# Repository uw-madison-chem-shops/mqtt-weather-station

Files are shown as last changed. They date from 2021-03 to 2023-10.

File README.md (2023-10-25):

# MQTT weather station

Simple station for monitoring environmental conditions in the lab over MQTT.

Based on the Bosch's [BME280 humidity, pressure, and temperature sensor](https://www.bosch-sensortec.com/products/environmental-sensors/humidity-sensors-bme280/).
Using Adafruit's [breakout board](https://www.adafruit.com/product/2652).

Designed to work with [mqtt.chem.wisc.edu](https://mqtt.chem.wisc.edu/).

## Repository

This is an open source hardware project licensed under the CERN Open Hardware Licence Version 2 - Permissive.
Please see the LICENSE file for the complete license.

This repository is being mirrored to several version control systems in an attempt to ensure maximum avaliability.

| name | url |
| --- | --- |
| blaise | https://git.blaise.zone/uw-madison-chem-shops/mqtt-weather-station.git/about/ |
| Codeberg | https://codeberg.org/uw-madison-chem-shops/mqtt-weather-station |
| GitHub (primary) | https://github.com/uw-madison-chem-shops/mqtt-weather-station |
| GitLab | https://gitlab.com/uw-madison-chem-shops/mqtt-weather-station |

## PCB

This PCB was designed using KiCAD version 5.
Refer to `weather.pdf` for schematic.
PCB images generated with [tracespace](https://github.com/tracespace/tracespace) follow.




## Bill of Materials

| reference | value | manufacturer | part number | price  | vendors |
| :--- | :--- | :--- | :--- | :----- | :--- |
| A1 | ESP8266 breakout | Adafruit | 2471 | $10.00 | [Adafruit](https://www.adafruit.com/product/2471) [DigiKey](https://www.digikey.com/en/products/detail/adafruit-industries-llc/2471/5355489) |
| C1 | 100u | Illinois Cap. | 107KXM025M | $0.25  | [DigiKey](https://www.digikey.com/en/products/detail/illinois-capacitor/107KXM025M/5410757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) |
| C2 | 10u | Yageo | CC1206KKX7R8BB106 | $0.25  | [DigiKey](https://www.digikey.com/en/products/detail/yageo/CC1206KKX7R8BB106/5195365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) |
| C3 | 22u | Yageo | CC1206MKX7R7BB226 | $0.75  | [DigiKey](https://www.digikey.com/en/products/detail/yageo/CC1206MKX7R7BB226/7071713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) |
| C4, C5 | 1u | | | | |
| D1, D2 | red LED | Lite-ON | LTST-C230KRKT | $0.50  | [DigiKey](https://www.digikey.com/en/products/detail/lite-on-inc/LTST-C230KRKT/386857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) |
| J1 | barrel jack | | | $1.00  | |
| PS1 | VXO7805-500-M | | | $3.00  | |
| Q1, Q2 | MOSFET N-ENH | Diodes Inc. | 2N7002K-7 | $0.25  | [DigiKey](https://www.digikey.com/en/products/detail/diodes-incorporated/2N7002K-7/1934378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) [Mouser](https://www.mouser.com/ProductDetail/Diodes-Incorporated/2N7002K-7?qs=rGAXPo9uwV0%2Fp9r5KJ7huA%3D%3D) |
| R1, R2 | 1k |
| R3, R4, R7, R8 | 4.7k |
| R5 | 470k |
| R6, R9 | 1M |
| U1 | BME280 breakout  | Adafruit | 2652 | $20.00 | [Adafruit](https://www.adafruit.com/product/2652) [DigiKey]() |
| U2 | counter | TI | CD4060BM96 | $0.50  |

All prices are extended.
Assuming an order of 10 PCBs, the boards themselves should cost around $5 each.

## Firmware

This project uses [micropython](https://micropython.org/), specifically [microhomie](https://github.com/microhomie/microhomie).
Refer to the "firmware" directory in this repository for detailed instructions.

## Changelog

#### Fixed
- value of C5

### Unprinted

### B

#### Added
- new hour long reset timer based on CD4060BM96

#### Changed
- SOT23 packages for all discrete transistors

### A

#### Added
- initial design

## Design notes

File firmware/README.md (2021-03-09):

# mqtt-weather-station firmware

This project uses [micropython](https://micropython.org/), specifically [microhomie](https://github.com/microhomie/microhomie). Currently we build on microhomie-esp8266-v3.0.2, the binary is in the folder.

You must define the private information defined in `settings.py`. Copy `settings.py.example` to make a folder `settings.py` and define all relevant variables.

Run `flash.sh` to flash the board. You will need [esptool](https://github.com/espressif/esptool) and [ampy](https://github.com/scientifichackers/ampy).

We recommend an [FTDI Basic Breakout](https://www.sparkfun.com/products/9716) to physically program the ESP8266.

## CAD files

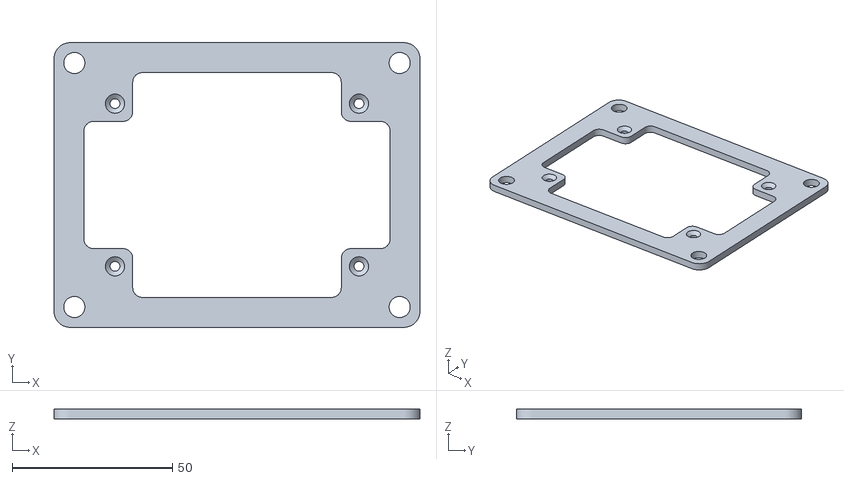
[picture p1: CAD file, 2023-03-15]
adapter-plate/adapter-plate.stl
114.3 x 88.9 x 3.00

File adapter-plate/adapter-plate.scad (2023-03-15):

$fn=50;
inch = 25.4;

module roundedRect(size, radius)
{
        x = size[0];
        y = size[1];
        z = size[2];

        linear_extrude(height=z)
        hull()
        {
                // place 4 circles in the corners, with the given radius
                translate([(-x/2)+radius, (-y/2)+radius, 0])
                circle(r=radius);

                translate([(x/2)-radius, (-y/2)+radius, 0])
                circle(r=radius);

                translate([(-x/2) + radius, (y/2)-radius, 0])
                circle(r=radius);

                translate([(x/2)-radius, (y/2)-radius, 0])
                circle(r=radius);
        }

}

module counterSunk(position, radius)
{
union()
    {
     translate(position)
     union()
        {
     cylinder(3, radius, radius, 8, center=false);
     cylinder(3, 0, 3, center=false);
        }
    }
    
}

difference()
{
roundedRect([4.5*inch, 3.5*inch, 3], 5, center=false);

translate([-4*inch/2, -3*inch/2, 0])
cylinder(3, 0.13*inch, 0.13*inch, 8, center=false);
    
translate([-4*inch/2, 3*inch/2, 0])
cylinder(3, 0.13*inch, 0.13*inch, 8, center=false);
    
translate([4*inch/2, -3*inch/2, 0])
cylinder(3, 0.13*inch, 0.13*inch, 8, center=false);
    
translate([4*inch/2, 3*inch/2, 0])
cylinder(3, 0.13*inch, 0.13*inch, 8, center=false);

counterSunk([3*inch/2, 2*inch/2, 0], 0.06*inch);
counterSunk([-3*inch/2, 2*inch/2, 0], 0.06*inch);
counterSunk([3*inch/2, -2*inch/2, 0], 0.06*inch);
counterSunk([-3*inch/2, -2*inch/2, 0], 0.06*inch);



linear_extrude(height=5)
offset(r=3){
offset(r=-6){
union(){
square([4*inch,1.8*inch], center=true);
square([2.8*inch,3*inch], center=true);
}
}
}
}

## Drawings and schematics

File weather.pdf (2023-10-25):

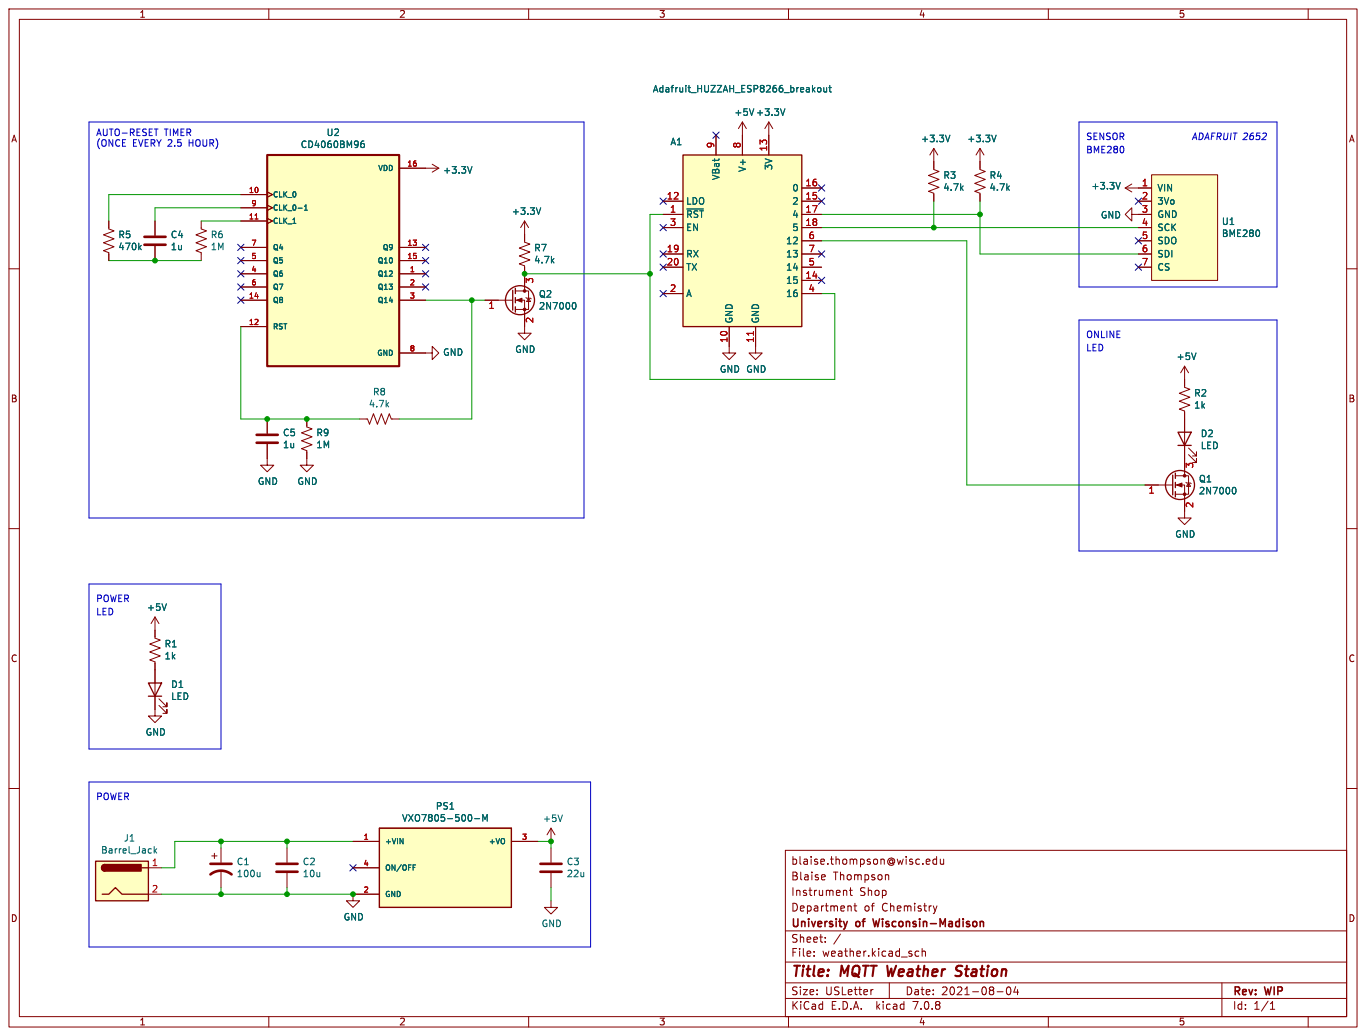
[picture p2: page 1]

ADAFRUIT 2652 AUTO-RESET TIMER

blaise.thompson@wisc.edu

Id: 1/1 Title: MQTT Weather Station

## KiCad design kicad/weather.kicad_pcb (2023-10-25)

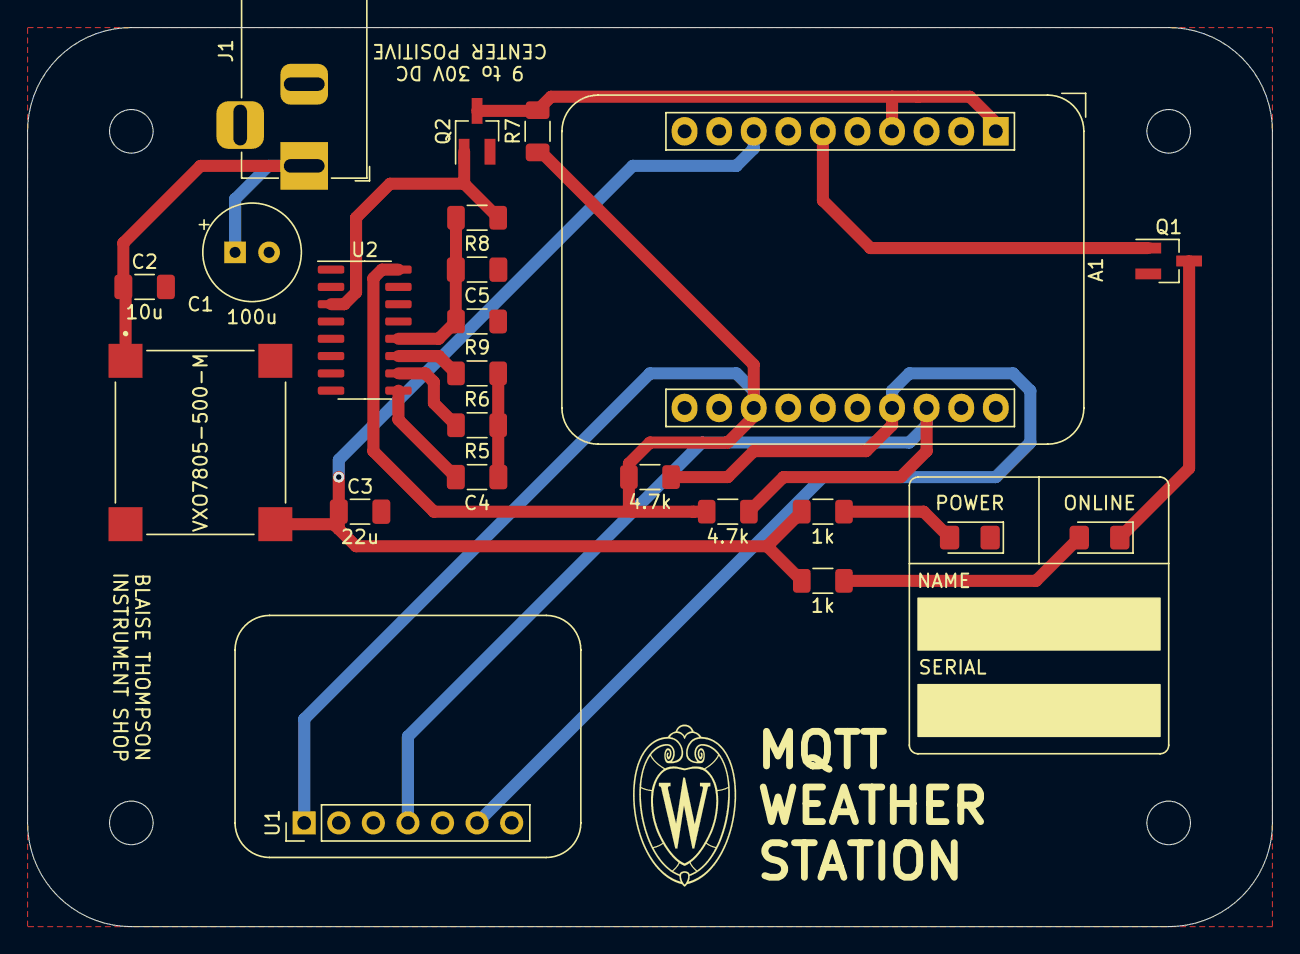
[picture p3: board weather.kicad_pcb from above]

Board: 2 copper layers, 91.4 x 66.0 mm, 23 parts (0 on the bottom side), 17 nets.

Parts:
A1: Adafruit_HUZZAH_ESP8266_breakout
C1: 100u; CP_Radial_Tantal_D7.0mm_P2.50mm
C2: 10u; C_1206_3216Metric_Pad1.33x1.80mm_HandSolder
C3: 22u; C_1206_3216Metric_Pad1.33x1.80mm_HandSolder
C4: 1n; C_1206_3216Metric_Pad1.33x1.80mm_HandSolder
C5: C; C_1206_3216Metric_Pad1.33x1.80mm_HandSolder
D1, D2: LED; LED_1206_3216Metric_Pad1.42x1.75mm_HandSolder
J1: Barrel_Jack; BarrelJack_Horizontal
PS1: VXO7805-500-M; CONV_VXO7805-500-M
Q1, Q2: 2N7000; SOT-23_Handsoldering
R1, R2: 1k; R_1206_3216Metric_Pad1.30x1.75mm_HandSolder
R3, R4: 4.7k; R_1206_3216Metric_Pad1.30x1.75mm_HandSolder
R5: 100k; R_1206_3216Metric_Pad1.30x1.75mm_HandSolder
R6: 1M; R_1206_3216Metric_Pad1.30x1.75mm_HandSolder
R7, R8, R9: R_US; R_1206_3216Metric_Pad1.30x1.75mm_HandSolder
U1: BME280; PinHeader_1x07_P2.54mm_Vertical
U2: CD4060BM96; SOIC-16_3.9x9.9mm_P1.27mm

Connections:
+3V3: A1.13, R3.1, R4.1, R7.1, U1.1, U2.16
+5V: A1.8, C3.1, PS1.3, R1.1, R2.1
GND: A1.10, A1.11, C1.2, C2.2, C3.2, C5.2, D1.1, J1.2, PS1.2, Q1.2, Q2.2, R9.2, U1.3, U2.8
unnamed: A1.1, A1.4, Q2.3, R7.2
unnamed: A1.6, Q1.1
unnamed: A1.17, R4.2, U1.6
unnamed: A1.18, R3.2, U1.4
unnamed: C1.1, C2.1, J1.1, PS1.1
unnamed: C4.1, U2.9
unnamed: C4.2, R5.1, R6.1
unnamed: C5.1, R8.2, R9.1, U2.12
unnamed: D1.2, R1.2
unnamed: D2.1, Q1.3
unnamed: D2.2, R2.2
unnamed: Q2.1, R8.1, U2.3
unnamed: R5.2, U2.10
unnamed: R6.2, U2.11

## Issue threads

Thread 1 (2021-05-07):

Q1 pin assignments wrong

untzag, 2021-05-07:
I believe the pin assignments for Q1 are wrong---should look more closely.

Closed 2021-08-04.

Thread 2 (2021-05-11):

C4 incorrect value for time constant

leobrunette, 2021-05-11:
C4 is currently 1nF which results in a time constant of 0.23ms. Desired time constant is 0.23s, to achieve C4 should be replaced with a 1uF capacitor.

Closed 2021-08-04.

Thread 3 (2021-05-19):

R5 value incorrect

leobrunette, 2021-05-19:
R5 value is currently 100k, this needs to be doubled (to obtain 1 hour reset).

untzag, 2021-05-25:
Correct value 470k

Closed 2021-05-25.

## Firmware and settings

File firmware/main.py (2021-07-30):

import settings

import sys
import machine
from machine import Pin, I2C, WDT
import network
import time
import struct

import mqtt_as
mqtt_as.MQTT_base.DEBUG = True


from bme280 import BME280

from homie.constants import FALSE, TRUE, BOOLEAN, FLOAT, STRING
from homie.device import HomieDevice
from homie.node import HomieNode
from homie.property import HomieNodeProperty

from uasyncio import get_event_loop, sleep_ms

class WeatherSensor(HomieNode):

    def __init__(self, name="bme280", device=None):
        super().__init__(id="bme280", name=name, type="sensor")
        self.device = device
        self.i2c = I2C(scl=Pin(5), sda=Pin(4))
        self.bme280 = BME280(i2c=self.i2c)
        self.temperature = HomieNodeProperty(
            id="temperature",
            name="temperature",
            unit="°C",
            settable=False,
            datatype=FLOAT,
            default=0,
        )
        self.add_property(self.temperature)
        self.humidity = HomieNodeProperty(
            id="humidity",
            name="humidity",
            unit="%",
            settable=False,
            datatype=FLOAT,
            default=0,
        )
        self.add_property(self.humidity)
        self.pressure = HomieNodeProperty(
            id="pressure",
            name="pressure",
            unit="Pa",
            settable=False,
            datatype=FLOAT,
            default=0,
        )
        self.add_property(self.pressure)
        self.uptime = HomieNodeProperty(
            id="uptime",
            name="uptime",
            settable=False,
            datatype=STRING,
            default="PT0S"
        )
        self.add_property(self.uptime)
        self.ip = HomieNodeProperty(
            id="ip",
            name="ip",
            settable=False,
            datatype=STRING,
            default="",
        )
        self.add_property(self.ip)
        self.led = Pin(0, Pin.OUT)
        self.online_led = Pin(12, Pin.OUT)
        self.online_led.off()
        self.last_online = time.time()
        self.start = time.time()
        print("start time", self.start)
        loop = get_event_loop()
        loop.create_task(self.update_data())

    async def update_data(self):
        # wait until connected
        for _ in range(60):
            print("wait until connected")
            await sleep_ms(1_000)
            if self.device.mqtt.isconnected():
                break
        # do 5 measurements to "warm up" the sensor
        #    for whatever reason the first measurements after poweron are systematically wrong
        #    I do not understand why
        #    --- Blaise 2021-07-30
        for _ in range(5):
            _ = self.bme280.temperature
            _ = self.bme280.humidity
            _ = self.bme280.pressure
            await sleep_ms(500)
        # loop forever
        while True:
            while self.device.mqtt.isconnected():
                print("update data")
                print(network.WLAN().status())
                self.last_online = time.time()
                print(1)
                self.online_led.on()
                print(2)
                self.led.value(0)  # illuminate onboard LED
                self.temperature.data = str(self.bme280.temperature)
                self.humidity.data = str(self.bme280.humidity)
                self.pressure.data = str(self.bme280.pressure)
                self.uptime.data = self.get_uptime()
                self.ip.data = network.WLAN().ifconfig()[0]
                self.led.value(1)  # onboard LED off
                print("final")
                await sleep_ms(15_000)
            while not self.device.mqtt.isconnected():
                print("wait for reconnect")
                if time.time() - self.last_online > 300:   # 5 minutes
                    machine.reset()
                self.online_led.off()
                self.led.value(0)  # illuminate onboard LED
                await sleep_ms(100)
                self.led.value(1)  # onboard LED off
                await sleep_ms(1000)
            machine.reset()  # if lost connection, restart

    def get_uptime(self):
        diff = int(time.time() - self.start)
        out = "PT"
        # hours
        if diff // 3600:
            out += str(diff // 3600) + "H"
            diff %= 3600
        # minutes
        if diff // 60:
            out += str(diff // 60) + "M"
            diff %= 60
        # seconds
        out += str(diff) + "S"
        return out

def main():
    # homie
    print("homie main")
    homie = HomieDevice(settings)
    homie.add_node(WeatherSensor(device=homie))
    homie.run_forever()

if __name__ == "__main__":
    main()

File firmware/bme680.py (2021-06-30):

# Spaces, comments and some functions have been removed from the original file to save memory
# Original source: https://github.com/adafruit/Adafruit_CircuitPython_BME680/blob/master/adafruit_bme680.py
import time
import math
from micropython import const
from ubinascii import hexlify as hex
try:
  import struct
except ImportError:
  import ustruct as struct
_BME680_CHIPID = const(0x61)
_BME680_REG_CHIPID = const(0xD0)
_BME680_BME680_COEFF_ADDR1 = const(0x89)
_BME680_BME680_COEFF_ADDR2 = const(0xE1)
_BME680_BME680_RES_HEAT_0 = const(0x5A)
_BME680_BME680_GAS_WAIT_0 = const(0x64)
_BME680_REG_SOFTRESET = const(0xE0)
_BME680_REG_CTRL_GAS = const(0x71)
_BME680_REG_CTRL_HUM = const(0x72)
_BME280_REG_STATUS = const(0xF3)
_BME680_REG_CTRL_MEAS = const(0x74)
_BME680_REG_CONFIG = const(0x75)
_BME680_REG_PAGE_SELECT = const(0x73)
_BME680_REG_MEAS_STATUS = const(0x1D)
_BME680_REG_PDATA = const(0x1F)
_BME680_REG_TDATA = const(0x22)
_BME680_REG_HDATA = const(0x25)
_BME680_SAMPLERATES = (0, 1, 2, 4, 8, 16)
_BME680_FILTERSIZES = (0, 1, 3, 7, 15, 31, 63, 127)
_BME680_RUNGAS = const(0x10)
_LOOKUP_TABLE_1 = (2147483647.0, 2147483647.0, 2147483647.0, 2147483647.0, 2147483647.0,
  2126008810.0, 2147483647.0, 2130303777.0, 2147483647.0, 2147483647.0,
  2143188679.0, 2136746228.0, 2147483647.0, 2126008810.0, 2147483647.0,
  2147483647.0)
_LOOKUP_TABLE_2 = (4096000000.0, 2048000000.0, 1024000000.0, 512000000.0, 255744255.0, 127110228.0,
  64000000.0, 32258064.0, 16016016.0, 8000000.0, 4000000.0, 2000000.0, 1000000.0,
  500000.0, 250000.0, 125000.0)
def _read24(arr):
  ret = 0.0
  for b in arr:
    ret *= 256.0
    ret += float(b & 0xFF)
  return ret
class Adafruit_BME680:
  def __init__(self, *, refresh_rate=10):
    self._write(_BME680_REG_SOFTRESET, [0xB6])
    time.sleep(0.005)
    chip_id = self._read_byte(_BME680_REG_CHIPID)
    if chip_id != _BME680_CHIPID:
      raise RuntimeError('Failed 0x%x' % chip_id)
    self._read_calibration()
    self._write(_BME680_BME680_RES_HEAT_0, [0x73])
    self._write(_BME680_BME680_GAS_WAIT_0, [0x65])
    self.sea_level_pressure = 1013.25
    self._pressure_oversample = 0b011
    self._temp_oversample = 0b100
    self._humidity_oversample = 0b010
    self._filter = 0b010
    self._adc_pres = None
    self._adc_temp = None
    self._adc_hum = None
    self._adc_gas = None
    self._gas_range = None
    self._t_fine = None
    self._last_reading = 0
    self._min_refresh_time = 1000 / refresh_rate
  @property
  def pressure_oversample(self):
    return _BME680_SAMPLERATES[self._pressure_oversample]
  @pressure_oversample.setter
  def pressure_oversample(self, sample_rate):
    if sample_rate in _BME680_SAMPLERATES:
      self._pressure_oversample = _BME680_SAMPLERATES.index(sample_rate)
    else:
      raise RuntimeError("Invalid")
  @property
  def humidity_oversample(self):
    return _BME680_SAMPLERATES[self._humidity_oversample]
  @humidity_oversample.setter
  def humidity_oversample(self, sample_rate):
    if sample_rate in _BME680_SAMPLERATES:
      self._humidity_oversample = _BME680_SAMPLERATES.index(sample_rate)
    else:
      raise RuntimeError("Invalid")
  @property
  def temperature_oversample(self):
      return _BME680_SAMPLERATES[self._temp_oversample]
  @temperature_oversample.setter
  def temperature_oversample(self, sample_rate):
    if sample_rate in _BME680_SAMPLERATES:
      self._temp_oversample = _BME680_SAMPLERATES.index(sample_rate)
    else:
      raise RuntimeError("Invalid")
  @property
  def filter_size(self):
    return _BME680_FILTERSIZES[self._filter]
  @filter_size.setter
  def filter_size(self, size):
    if size in _BME680_FILTERSIZES:
      self._filter = _BME680_FILTERSIZES[size]
    else:
      raise RuntimeError("Invalid")
  @property
  def temperature(self):
    self._perform_reading()
    calc_temp = (((self._t_fine * 5) + 128) / 256)
    return calc_temp / 100
  @property
  def pressure(self):
    self._perform_reading()
    var1 = (self._t_fine / 2) - 64000
    var2 = ((var1 / 4) * (var1 / 4)) / 2048
    var2 = (var2 * self._pressure_calibration[5]) / 4
    var2 = var2 + (var1 * self._pressure_calibration[4] * 2)
    var2 = (var2 / 4) + (self._pressure_calibration[3] * 65536)
    var1 = (((((var1 / 4) * (var1 / 4)) / 8192) *
      (self._pressure_calibration[2] * 32) / 8) +
      ((self._pressure_calibration[1] * var1) / 2))
    var1 = var1 / 262144
    var1 = ((32768 + var1) * self._pressure_calibration[0]) / 32768
    calc_pres = 1048576 - self._adc_pres
    calc_pres = (calc_pres - (var2 / 4096)) * 3125
    calc_pres = (calc_pres / var1) * 2
    var1 = (self._pressure_calibration[8] * (((calc_pres / 8) * (calc_pres / 8)) / 8192)) / 4096
    var2 = ((calc_pres / 4) * self._pressure_calibration[7]) / 8192
    var3 = (((calc_pres / 256) ** 3) * self._pressure_calibration[9]) / 131072
    calc_pres += ((var1 + var2 + var3 + (self._pressure_calibration[6] * 128)) / 16)
    return calc_pres  # Pa
  @property
  def humidity(self):
    self._perform_reading()
    temp_scaled = ((self._t_fine * 5) + 128) / 256
    var1 = ((self._adc_hum - (self._humidity_calibration[0] * 16)) -
      ((temp_scaled * self._humidity_calibration[2]) / 200))
    var2 = (self._humidity_calibration[1] *
      (((temp_scaled * self._humidity_calibration[3]) / 100) +
       (((temp_scaled * ((temp_scaled * self._humidity_calibration[4]) / 100)) /
         64) / 100) + 16384)) / 1024
    var3 = var1 * var2
    var4 = self._humidity_calibration[5] * 128
    var4 = (var4 + ((temp_scaled * self._humidity_calibration[6]) / 100)) / 16
    var5 = ((var3 / 16384) * (var3 / 16384)) / 1024
    var6 = (var4 * var5) / 2
    calc_hum = (((var3 + var6) / 1024) * 1000) / 4096
    calc_hum /= 1000
    if calc_hum > 100:
      calc_hum = 100
    if calc_hum < 0:
      calc_hum = 0
    return calc_hum
  @property
  def altitude(self):
    pressure = self.pressure
    return 44330 * (1.0 - math.pow(pressure / self.sea_level_pressure, 0.1903))
  @property
  def gas(self):
    self._perform_reading()
    var1 = ((1340 + (5 * self._sw_err)) * (_LOOKUP_TABLE_1[self._gas_range])) / 65536
    var2 = ((self._adc_gas * 32768) - 16777216) + var1
    var3 = (_LOOKUP_TABLE_2[self._gas_range] * var1) / 512
    calc_gas_res = (var3 + (var2 / 2)) / var2
    return int(calc_gas_res)
  def _perform_reading(self):
    if (time.ticks_diff(self._last_reading, time.ticks_ms()) * time.ticks_diff(0, 1)
        < self._min_refresh_time):
      return
    self._write(_BME680_REG_CONFIG, [self._filter << 2])
    self._write(_BME680_REG_CTRL_MEAS,
      [(self._temp_oversample << 5)|(self._pressure_oversample << 2)])
    self._write(_BME680_REG_CTRL_HUM, [self._humidity_oversample])
    self._write(_BME680_REG_CTRL_GAS, [_BME680_RUNGAS])
    ctrl = self._read_byte(_BME680_REG_CTRL_MEAS)
    ctrl = (ctrl & 0xFC) | 0x01
    self._write(_BME680_REG_CTRL_MEAS, [ctrl])
    new_data = False
    while not new_data:
      data = self._read(_BME680_REG_MEAS_STATUS, 15)
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

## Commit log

2021-04-06 organize repository
    [weather.kicad_pcb, weather.sch]
2021-05-25 after building one
    [weather.sch]
2023-03-15 slightly bigger holes adapter plate
    [adapter-plate.scad, adapter-plate.stl]
2023-10-25 C5 1u BOM
    [weather.kicad_pcb]
